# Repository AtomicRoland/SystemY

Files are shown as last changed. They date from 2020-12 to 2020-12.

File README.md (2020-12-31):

# SystemY
A keyboard, display and cassette interface for the Yarrb2 board.

When I designed the Yarrb2 board I kept in mind that it should be possible to use the board as a stand-alone system. Back then I already set my mind on making it some kind of System 1 clone. I explicitly say that this is a System1 clone and not a replica because the hardware doesn't look anything like an original System 1. Besides the original options like 1152 bytes RAM, 512 bytes ROM, 300 baud cassette, eight character display and 25 keys this version has the following additional options:

* The memory can be expanded to (almost) 60KB RAM and 4KB ROM (in the current CPLD version, you can of course expand it to 128K + 128K but that seems a bit overdone to me)
* RAM between #8000 - #EFFF can be write protected
* The reset button can be configured to generate an NMI or IRQ
* You have access to eight useless LEDs (because they are on the back side of the system)
* With a suitable CPU this system can run at 1, 2 of 4MHz
* The cassette output can be programmed to act like the Atom 1-bit audio

The cassette in-out is the most difficult part of the project and this is not working yet. I can output a 1200Hz and 2400Hz tone by clearing or setting bit 6 of port A (#E20) and when I save a block of data it sounds like there is a data stream. However, a connected Atom cannot load the data. Also writing to tape and reading back does not work. The CPLD will reset bit 7 of #E20 to 0 when there is a 1200Hz tone at the cassette input and set that bit to 1 if there is a 2400Hz tone. But reading data from an Atom, recorded tape or WAV file does not work although the signal looks nice on my oscilloscope.

And of course I had a lot of design mistakes on this board :shock: I forgot a series resistor for each digit, swapped inputs of the LM358 and I swapped the in and out of the cassette connector. Since I don't expect that somebody wants such a board I didn't mention it, but I record it here just to not forget these issues....

The KiCad files contain the diagram (also in PDF) and the gerber files.

## Copyright and disclosure

You are free to copy and use these files as you want to. However, I don't guarantee any support for your own projects.

The hardware and software in this project are as-is. No warranties, use at your own risk and do not use these in medical or life-supporting devices. Please don't blame me if something goes wrong.

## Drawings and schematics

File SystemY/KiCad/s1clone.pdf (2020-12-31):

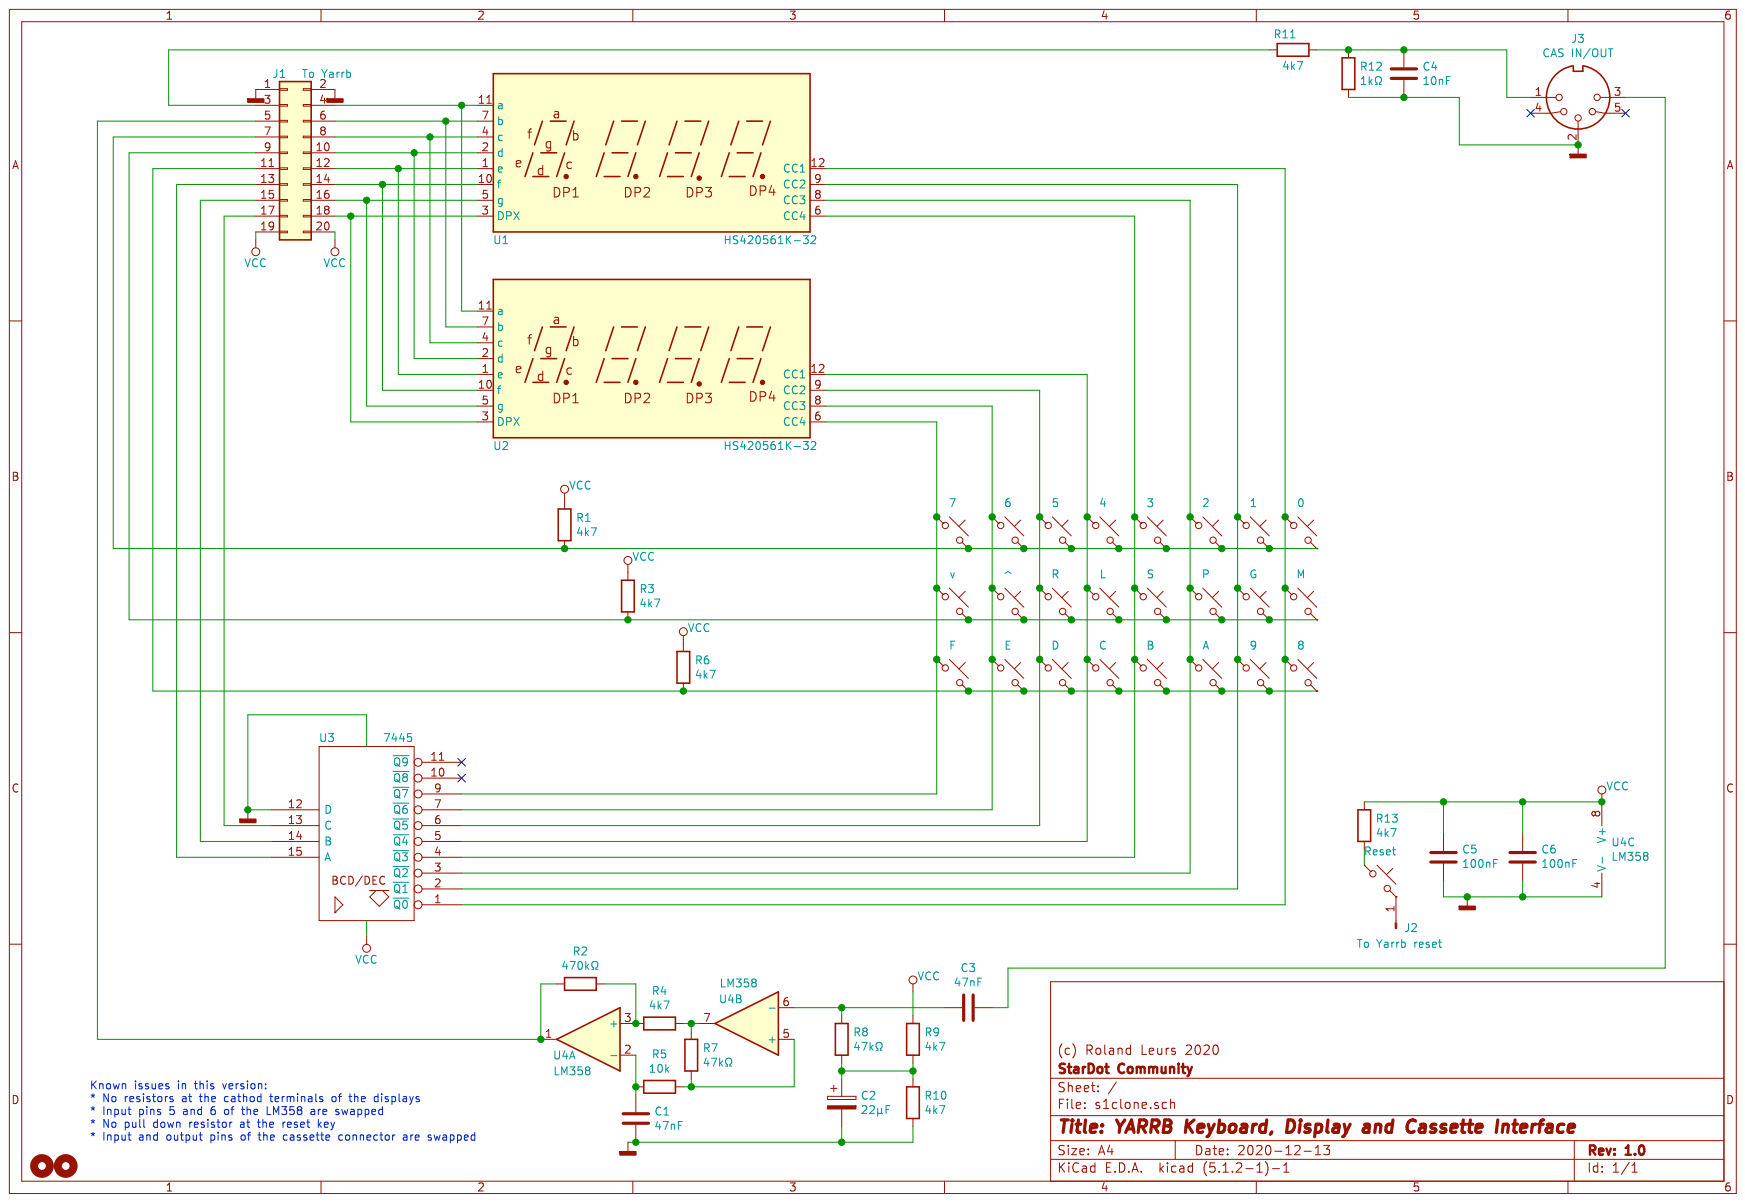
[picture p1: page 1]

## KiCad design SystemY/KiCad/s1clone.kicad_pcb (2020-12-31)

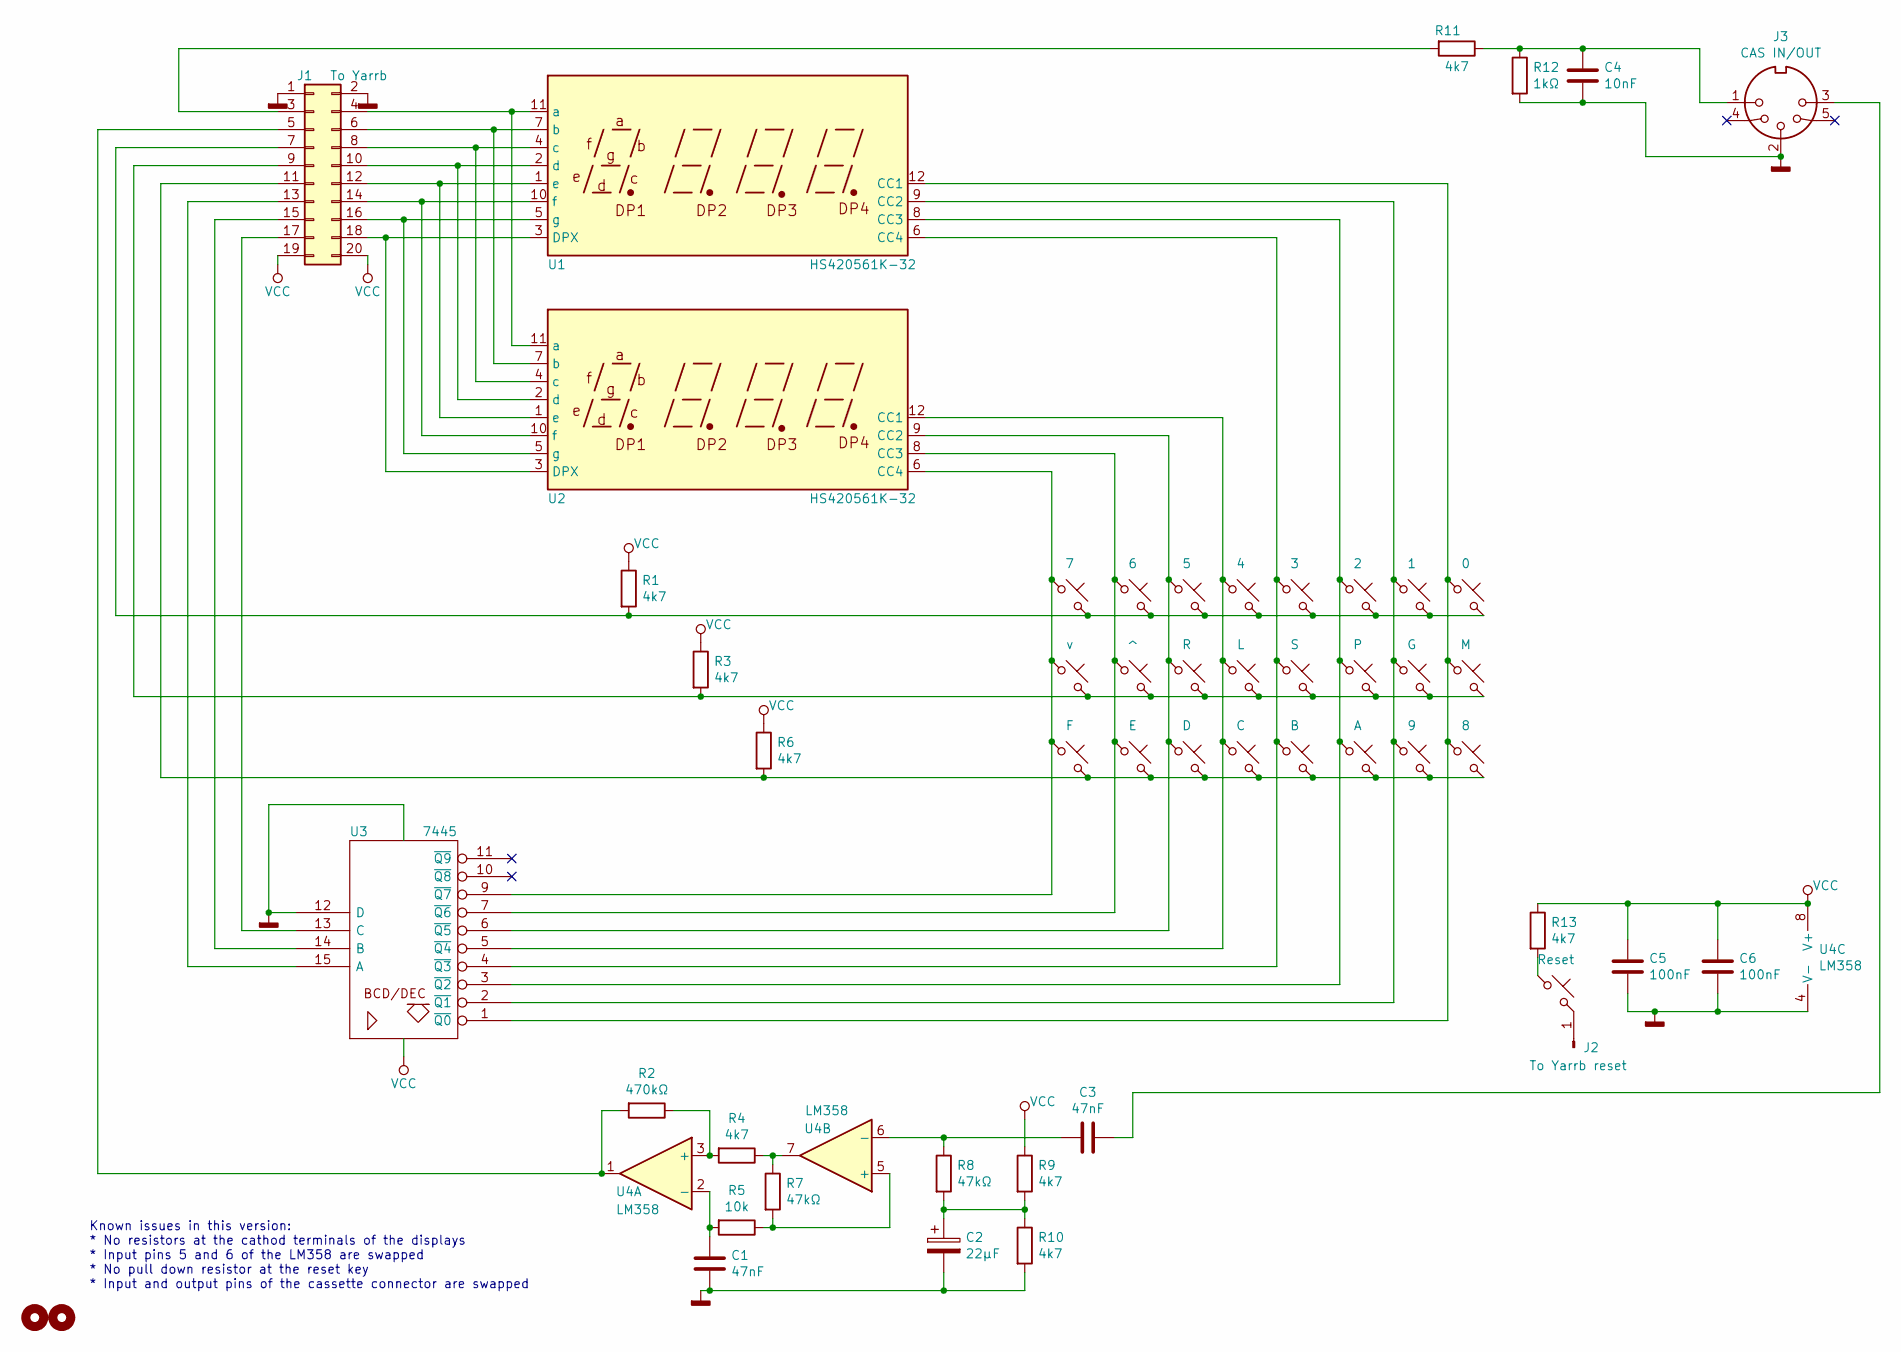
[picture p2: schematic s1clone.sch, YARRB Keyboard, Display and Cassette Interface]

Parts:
C1, C3: 47nF; C_Rect_L7.0mm_W3.5mm_P5.00mm
C2: 22µF; CP_Radial_D6.3mm_P2.50mm
C4: 10nF; C_Rect_L7.0mm_W3.5mm_P5.00mm
C5, C6: 100nF; C_Rect_L7.0mm_W3.5mm_P5.00mm
H1, H2: MountingHole; MountingHole_2.2mm_M2
J1: To Yarrb; PinHeader_2x10_P2.54mm_Vertical
J2: To Yarrb reset; PinHeader_1x01_P2.54mm_Vertical
J3: CAS IN/OUT; din-5
R1, R3, R4, R6, R9, R10, R11, R13: 4k7; R_Axial_DIN0411_L9.9mm_D3.6mm_P15.24mm_Horizontal
R2: 470kΩ; R_Axial_DIN0411_L9.9mm_D3.6mm_P15.24mm_Horizontal
R5: 10k; R_Axial_DIN0411_L9.9mm_D3.6mm_P15.24mm_Horizontal
R7, R8: 47kΩ; R_Axial_DIN0411_L9.9mm_D3.6mm_P15.24mm_Horizontal
R12: 1kΩ; R_Axial_DIN0411_L9.9mm_D3.6mm_P15.24mm_Horizontal
SW1: 7; SW_PUSH-12mm
SW2: v; SW_PUSH-12mm
SW3: F; SW_PUSH-12mm
SW4: 6; SW_PUSH-12mm
SW5: ^; SW_PUSH-12mm
SW6: E; SW_PUSH-12mm
SW7: 5; SW_PUSH-12mm
SW8: R; SW_PUSH-12mm
SW9: D; SW_PUSH-12mm
SW10: 4; SW_PUSH-12mm
SW11: L; SW_PUSH-12mm
SW12: C; SW_PUSH-12mm
SW13: 3; SW_PUSH-12mm
SW14: S; SW_PUSH-12mm
SW15: B; SW_PUSH-12mm
SW16: 2; SW_PUSH-12mm
SW17: P; SW_PUSH-12mm
SW18: A; SW_PUSH-12mm
SW19: 1; SW_PUSH-12mm
SW20: G; SW_PUSH-12mm
SW21: 9; SW_PUSH-12mm
SW22: 0; SW_PUSH-12mm
SW23: M; SW_PUSH-12mm
SW24: 8; SW_PUSH-12mm
SW25: Reset; SW_PUSH-12mm
U1, U2: HS420561K-32; CC56-12GWA
U3: 7445; DIP-16_W7.62mm_Socket
U4: LM358; DIP-8_W7.62mm_Socket

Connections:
GND: C1.2, C2.2, C4.2, C5.1, C6.1, J1.1, J1.2, J3.2, R10.2, R12.2, U3.8 (GND), U3.12 (D), U4.4 (V-)
unnamed: C1.1, R5.2, U4.2 (-)
unnamed: C2.1, R8.2, R9.2, R10.1
unnamed: C3.1, J3.3
unnamed: C3.2, R8.1, U4.6 (-)
unnamed: C4.1, J3.1, R11.1, R12.1
unnamed: J1.3, R11.2
unnamed: J1.4, U1.11 (a), U2.11 (a)
unnamed: J1.5, R2.2, U4.1
unnamed: J1.6, U1.7 (b), U2.7 (b)
unnamed: J1.7, R1.2, SW1.2, SW4.2, SW7.2, SW10.2, SW13.2, SW16.2, SW19.2, SW22.2
unnamed: J1.8, U1.4 (c), U2.4 (c)
unnamed: J1.9, R3.2, SW2.2, SW5.2, SW8.2, SW11.2, SW14.2, SW17.2, SW20.2, SW23.2
unnamed: J1.10, U1.2 (d), U2.2 (d)
unnamed: J1.11, R6.2, SW3.2, SW6.2, SW9.2, SW12.2, SW15.2, SW18.2, SW21.2, SW24.2
unnamed: J1.12, U1.1 (e), U2.1 (e)
unnamed: J1.13, U3.15 (A)
unnamed: J1.14, U1.10 (f), U2.10 (f)
unnamed: J1.15, U3.14 (B)
unnamed: J1.16, U1.5 (g), U2.5 (g)
unnamed: J1.17, U3.13 (C)
unnamed: J1.18, U1.3 (DPX), U2.3 (DPX)
unnamed: J2.1, SW25.2
unnamed: R2.1, R4.2, U4.3 (+)
unnamed: R4.1, R7.1, U4.7
unnamed: R5.1, R7.2, U4.5 (+)
unnamed: R13.2, SW25.1
unnamed: SW1.1, SW2.1, SW3.1, U2.6 (CC4), U3.9 (~Q7)
unnamed: SW4.1, SW5.1, SW6.1, U2.8 (CC3), U3.7 (~Q6)
unnamed: SW7.1, SW8.1, SW9.1, U2.9 (CC2), U3.6 (~Q5)
unnamed: SW10.1, SW11.1, SW12.1, U2.12 (CC1), U3.5 (~Q4)
unnamed: SW13.1, SW14.1, SW15.1, U1.6 (CC4), U3.4 (~Q3)
unnamed: SW16.1, SW17.1, SW18.1, U1.8 (CC3), U3.3 (~Q2)
unnamed: SW19.1, SW20.1, SW21.1, U1.9 (CC2), U3.2 (~Q1)
unnamed: SW22.1, SW23.1, SW24.1, U1.12 (CC1), U3.1 (~Q0)
VCC: C5.2, C6.2, J1.19, J1.20, R1.1, R3.1, R6.1, R9.1, R13.1, U3.16 (VCC), U4.8 (V+)

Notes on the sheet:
Known issues in this version: * No resistors at the cathod terminals of the displays * Input pins 5 and 6 of the LM358 are swapped * No pull down resistor at the reset key * Input and output pins of the cassette connector are swapped

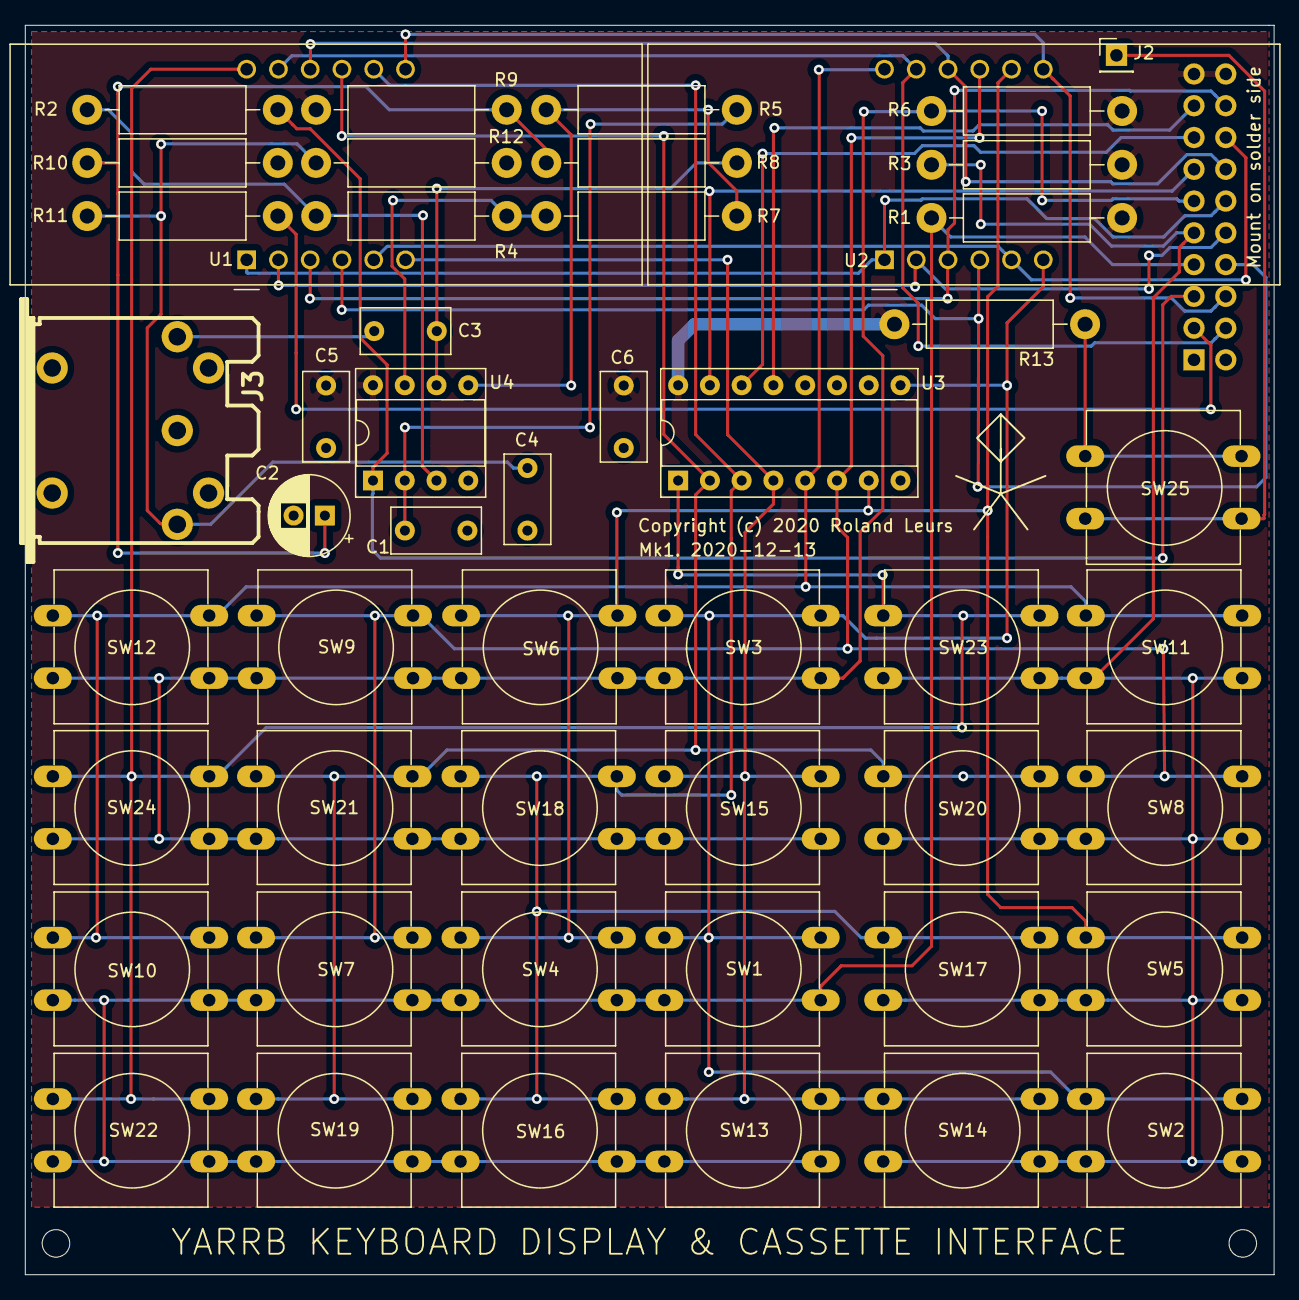
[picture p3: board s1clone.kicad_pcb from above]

Board: 2 copper layers, 99.9 x 99.9 mm, 53 parts (1 on the bottom side), 36 nets.

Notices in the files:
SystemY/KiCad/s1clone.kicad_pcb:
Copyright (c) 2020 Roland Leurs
